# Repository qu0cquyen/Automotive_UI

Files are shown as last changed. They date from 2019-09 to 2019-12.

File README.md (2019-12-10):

# Automotive_UI (Pulse Sensor - SEN 11574)
<html>
	<head></head>
	<body>
		<h3>System Diagram</h3><hr/>
		<p align='center'>Final</p>
		<h3>Introduction</h3> <hr/>
		<p>Pulse Sensor - SEN 11574 can be used to keep tracking the pulse and provide BMP (Beat per minute) readings which is useful under the medical circumstances when it comes to monitoring patient's health. In this document, I will be sharing my personal experience on how to create a development platform for obtaing the readings from the sensor. This document will only provide simple instructions and for study purpose.  </p>
		<h2>Table of Contents<hr/></h2>
		<ol>
			<li><a href='#Bud'>Budget</a></li>
			<li><a href='#TC'>Time Commitment</a></li>
			<li><a href='#MA'>Mechanical Assembly</a></li>
			<li><a href='#PCB'>PCB/Soldering</a></li>
			<li><a href='#PP'>Power Up and Production Testing</a></li>
			<li><a href='#EC'>Enclosure</a></li>
			<li><a href='#RF'>Reference</a></li>
		</ol>
	<ol>
		<li><h3 id='Bud'>Budget<hr/></h3></li>
		<p>To implement this project. There are some components and equipments are used: 
					<table>
						<tr><td>Raspberry Pi 4 - 32GB SDCard</td><td align="right">CDN$ 134.99</td></tr>
						<tr><td>ADS1015 Converter</td><td align="right">CDN$ 33.89</td></tr>
						<tr><td>Pulse Sensor - SEN 11574</td><td align="right">CDN$ 48.43</td></tr>
						<tr><td><a href='https://raw.githubusercontent.com/qu0cquyen/Automotive_UI/master/electronics/Project_Fritzing.fzz'>Customized PCB</a></td><td align="right">CDN$ 28.7</td></tr>
						<tr><td>Headers </td><td align="right">CDN$ 33.9</td></tr>
						<tr><td><a href='https://www.tinkercad.com/things/gwDEV7c7vIV-smashing-wolt/edit'>Customized Enclosure</a></td><td align="right">CDN$ 30.00</td></tr>
						<tr><td>Total</td><td align="right">CDN$ 308.82</td></tr>
					</table>
			The total price is assumed that we do not possess any components aside from Standley tool kit (included jumper wires)
		</p>
		<li><h3 id='TC'>Time Commitment<hr/></h3></li>
		<p>
		&emsp;&emsp;This time commitment is writtent based on the assumption of not having any components except the tool kit and no experience of PCB designing. The total amount of time to accomplish this project is approximately 31 hours. This included waiting time for all components and equipments are shipped and gathered. For some side-work such as Project Selection (30 minutes), Proposal, Meeting and Budget will take roughly one to two hours to finish each of them. </p>
		<p>&emsp;&emsp;Fritzing software is used to design the Breadboard and PCB. Both designs are pretty straight forward, all we need to do is to properly wire up all the components. However, the software does not include Hearbeat sensor and ADS1015 converter. You can download these 2 components for Fritizing with this links: 
		<ul>
			<li><a href='https://raw.githubusercontent.com/adafruit/Fritzing-Library/master/parts/Adafruit%20ADS1015%2012Bit%20I2C%20ADC.fzpz'>ADS1015</a></li>
			<li><a href='https://raw.githubusercontent.com/WorldFamousElectronics/Fritzing_PulseSensor_Files/master/Pulse%20Sensor.fzpz'>Pulse Sensor</a></li>
		</ul>
		In additional, there are two things we need to adjust for the PCB design are the size of Vias and Wires, 0.9 and 16 mil accordingly. This process should take around 4 hours. A personal design can be found from this <a href='https://github.com/qu0cquyen/Automotive_UI/blob/master/electronics/Project_Fritzing.fzz'>link</a>. </p>
		<p>&emsp;&emsp;After having both designs are done, next all the necessary components will be hooked up on the breadboard first based upon the breadboard designed which is done on Fritizing. The amount of time should be spent on this process is 30 minutes to 1 hour. </p>
		<p>&emsp;&emsp;Once we have everything ready up to this point, building an enclosure for our components will be our next step. Personally, this can be seen as the most annoyed process in the whole project; apart from coming up with a design which can cover all the parts of our components, we also need to have a inctricate design in order to fit in all the parts together. In this process I spent about 21 hours for both designing and 3D printing the enclosure. During the process, I used school and 3rd-party 3D printing service outside the school to accelerate my process. There is a number of faulty designs have been made due to mistaking measurements, therefore, I would recommend that you should research or ask experts who are able to give some suggestions in details measurement, if you want all the parts of the enclosure can perfectly fit to each other.</p>
		<li><h3 id='MA'>Mechanical Assembly<hr/></h3></li>
		<p>In order to get the reading from the sensor. There are several steps we should take to create our development platform.</p>
		<h4>Step 1: Download and Install IOS for Raspberry Pi.</h4>
		<p>The image that we are going to use for our Pi is Raspbian. You can download from this <a href='https://downloads.raspberrypi.org/raspbian_full/images/raspbian_full-2019-09-30/2019-09-26-raspbian-buster-full.zip'>link</a></p>
		<p>Aside from downloading the image, we also need to download another software which helps to write the image to a SD card and this card is used by the Raspberry Pi.  You can download from here: https://www.balena.io/etcher/</p>
		<p align='center'>animated</p>
		<h4>Step 2: Boost up Operating System</h4>
		<p>After writing the image to the SD card, it is time to boost up our Pi Operating System. First, we need to do some configuration if you want your Pi to be able to work remotely.</p>
		<p>&emsp;&emsp;- Open the terminal and type in: <b>sudo raspi-config</b></p>
		
		
		<p>&emsp;&emsp;&emsp;&emsp;Enable SSH, VNC and I2C features</p>
		<p>&emsp;&emsp;- Next we will set up the WIFI: </p>
		<p>&emsp;&emsp;&emsp;&emsp;In the terminal type in: <b>sudo nano /etc/wpa_supplicant/wpa_supplicant.conf</b></p>
		<p>&emsp;&emsp;&emsp;&emsp;&emsp;&emsp;Types in the following lines: </p>
		<p>&emsp;&emsp;&emsp;&emsp;&emsp;&emsp;&emsp;&emsp;<b>network={<br/>
		&emsp;&emsp;&emsp;&emsp;&emsp;&emsp;&emsp;&emsp;&emsp;&emsp;&emsp;&emsp;&emsp;&emsp;ssid="YOUR WIFI NAME"<br/>
		&emsp;&emsp;&emsp;&emsp;&emsp;&emsp;&emsp;&emsp;&emsp;&emsp;&emsp;&emsp;&emsp;&emsp;password="WIFI PASSWORD"<br/>
		&emsp;&emsp;&emsp;&emsp;&emsp;&emsp;&emsp;&emsp;&emsp;&emsp;&emsp;&emsp;&emsp;&emsp;priority=999<br/>
		&emsp;&emsp;&emsp;&emsp;&emsp;&emsp;&emsp;&emsp;&emsp;&emsp;&emsp;&emsp;&emsp;}</b></p>
		<p>&emsp;&emsp;Notice the "priority" line, when you implement this line the Raspberry Pi will look for the network which has the highest priority first to connect, if the network is not avaiable it will automatic connect to any network that has accessed before.</p>
		<h4>Step 3: Assemble our components to Pi: </h4>
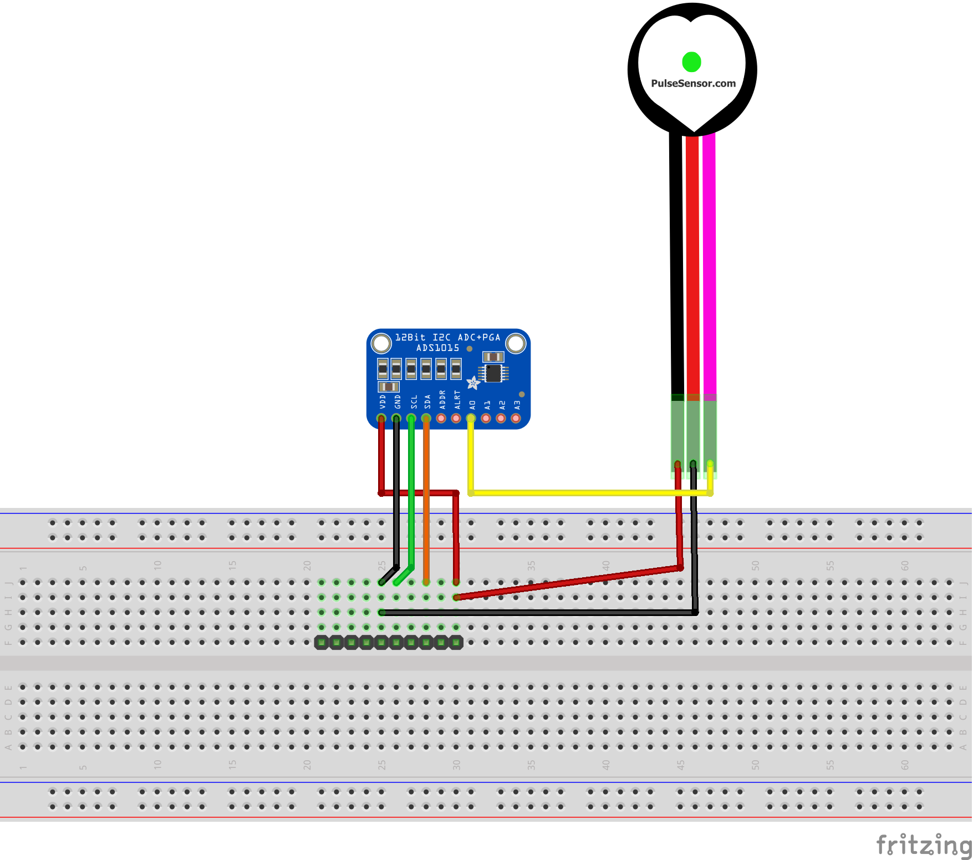
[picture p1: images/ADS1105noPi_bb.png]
		
		
		<h4>Step 4: Coding</h4>
		<p>&emsp;&emsp;You can refer to the code fragment from here: https://github.com/udayankumar/heart-rate-raspberry-pi. Code is written by using Python language.</p>
		<h4>Step 5: Result</h4>
		<p>&emsp;&emsp;If you are flowing those steps above, you should be able to get the reading from the sensor.</p>
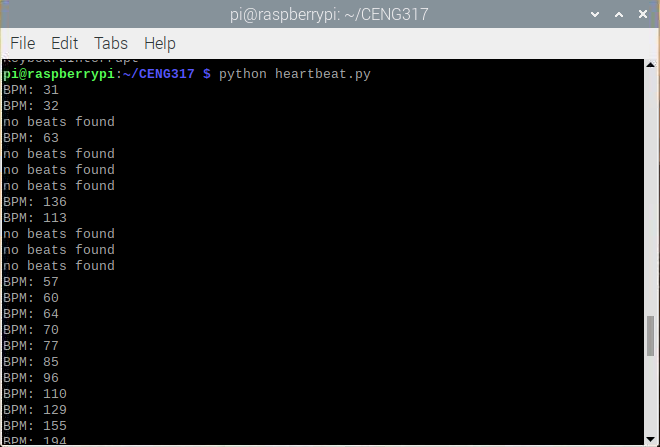
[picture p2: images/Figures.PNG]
		
		<li><h3 id='PCB'>PCB/Soldering<hr/></h3></li>
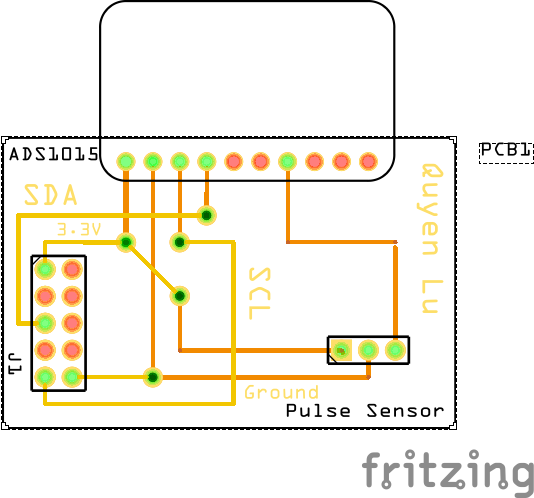
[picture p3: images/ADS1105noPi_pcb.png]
		
		
		<li><h3 id='PP'>Power Up and Production Testing<hr/></h3></li>
		
		<p>&emsp;&emsp;The picture above shows the voltage measurement that I measured on PCB section where the header connects to the Pi, and the Pi supplies the voltage for PCB in order to connect the remainder parts on the PCB board. Since I am using 3.3V to power up my PCB; therefore, when I measure the voltage on the other side of the PCB, the voltage meter gives me the reading of 3.3V.</p>
		
		<p>&emsp;&emsp;I did the same procedure of measuring as I mentioned above, however, this time I measured at the Sensor part. This measurement demonstrates that all the sections on the PCB are connected to each other, since I am able to get voltage reading (3.3V) when I measure on the Sensor part. This means the Pi is providing 3.3V for the whole PCB. </p>
		
		<p>&emsp;&emsp;When everything is connected to each other, you will be able to see the light on the Sensor is up. </p>
		
		<p>&emsp;&emsp;After having everything is hooked up, this is the phase that I tested whether or not my Sensor is working properly. By getting the BMP on the terminal, this proves that my Sensor is working as I expected by displaying the BMP when I place my finger on the Sensor.</p>
		<li><h3 id='EC'>Enclosure<hr/></h3></li>
		<p>&emsp;&emsp;To design the Enclosure, you can use either Sketchup or Tinkercad to desgin your own enclosure. After your design is done, you should generate a .STL file and feed to Cura - A software which is used for 3D printing purpose. Cura will provide us an insight information what need to be used/done in order to print out the real case. When you finish revewing configuration information, Cura can help you export a .G file which is used for 3D printer to continue printing our work. The printing process usually takes up around from 2 upto 8 hours depends on your design. Finally, when we have our case is properly printed, it is time to put our components into the enclosure. The images below is my personal enclosure. <b>Notice: There is still some minor mistakes, please reconsider if you are going to use this design.</b> You can find my design files here:
			<a href='https://github.com/qu0cquyen/Automotive_UI/blob/master/mechanical/Final_Bottom_Case_Enclousre.stl'>Bottom</a>
		<a href='https://github.com/qu0cquyen/Automotive_UI/blob/master/mechanical/Final_Middle_Case_Enclosure.stl'>Top</a></p>
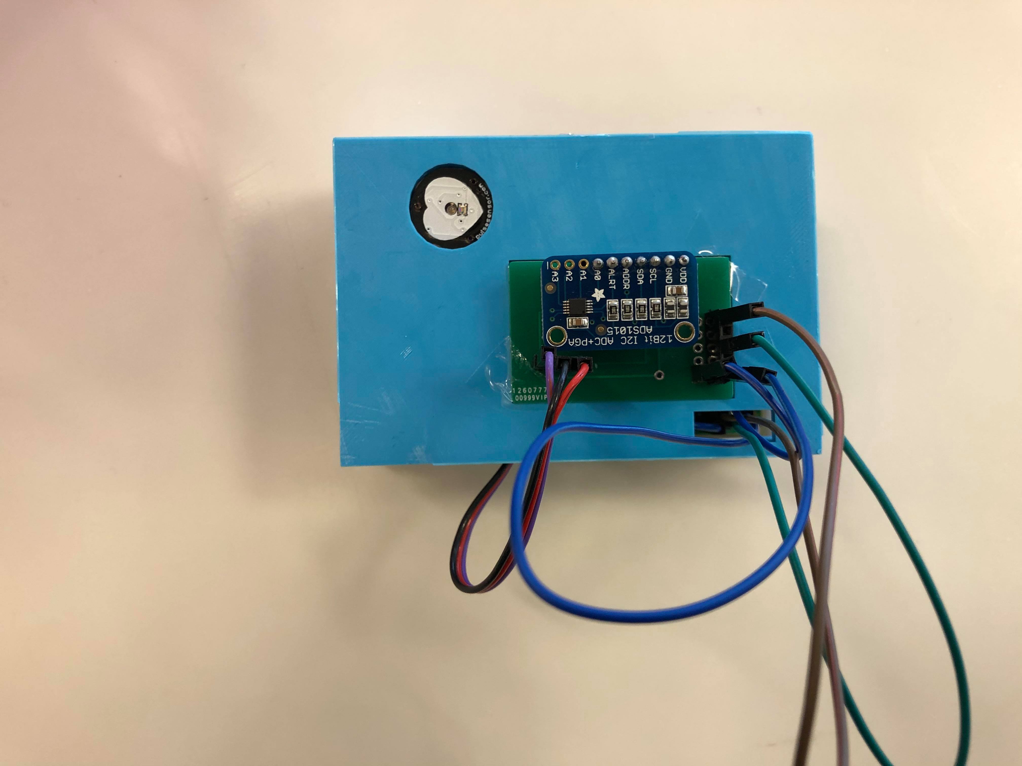
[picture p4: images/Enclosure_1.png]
		
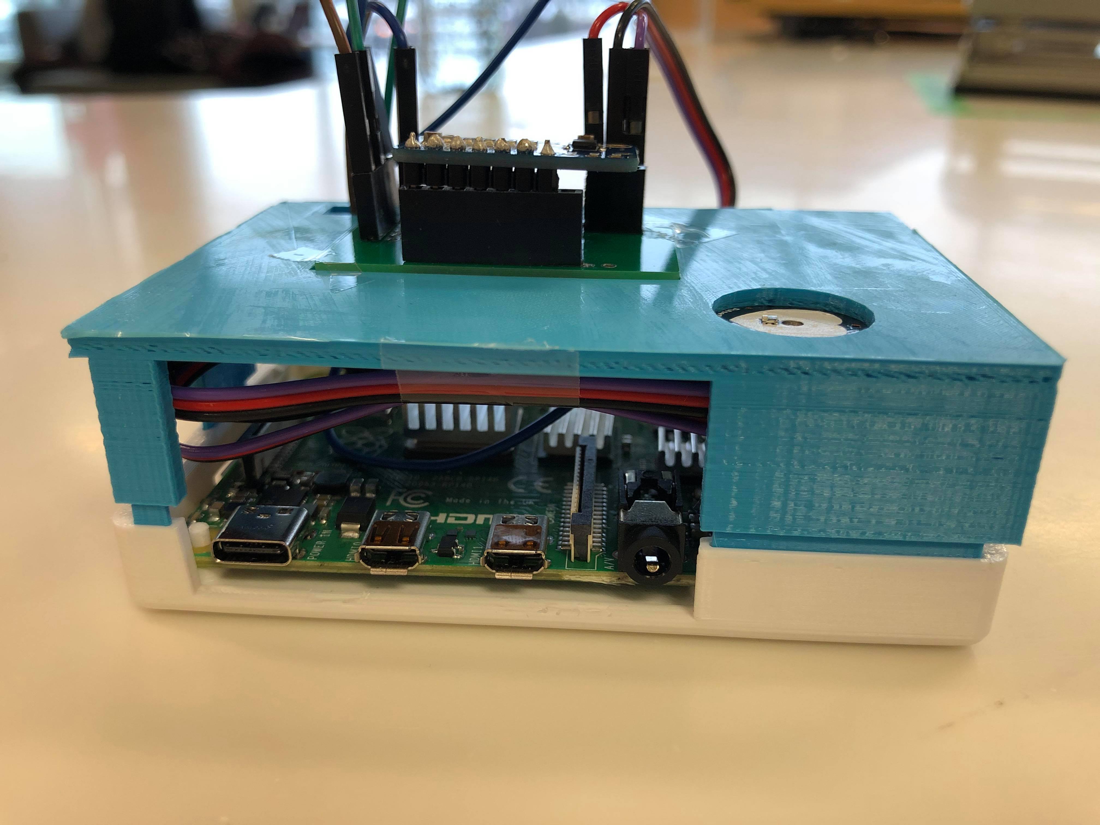
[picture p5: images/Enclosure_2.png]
		
	<li><h3 id='RF'>Reference: <hr/></h3></li>
	<p>Marinos, A. (2018, October 18). Etcher: Now with multi-write and Compute Module support! Retrieved from https://www.balena.io/blog/etcher-now-with-multi-write-and-compute-module-support/.</p>
	<p>Staff, M. (2018, April 5). How to Boot to Command Line and SSH on Raspberry Pi. Retrieved from https://www.digikey.com/en/maker/blogs/2018/how-to-boot-to-command-line-and-ssh-on-raspberry-pi.</p>
	</ol>
	</body> 
</html>

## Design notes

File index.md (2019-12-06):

<!DOCTYPE html> 
<html>
	<head>
	</head>
	<body>
		<h2>Blog Project CENG317 </h2>
		<h3>December 5th, 2019</h3>
		<p>Uploads final enclosures design files</p>
		<a href='https://github.com/qu0cquyen/Automotive_UI/blob/master/mechanical/Final_Bottom_Case_Enclousre.stl'>Bottom Enclosure</a><br/>
		<a href='https://github.com/qu0cquyen/Automotive_UI/blob/master/mechanical/Final_Middle_Case_Enclosure.stl'>Mid Enclosure</a>
		<h3>December 3rd, 2019</h3>
		<p>After carefully measuring, I have my final enclosure which holds my PCB and Heartrate sensor. The amount of time spending for this whole 3D printing process is approximately 21 hours (included the failed printing)</p>
		<p>These pictures are my final enclosure: </p>
		<ul>
			
			
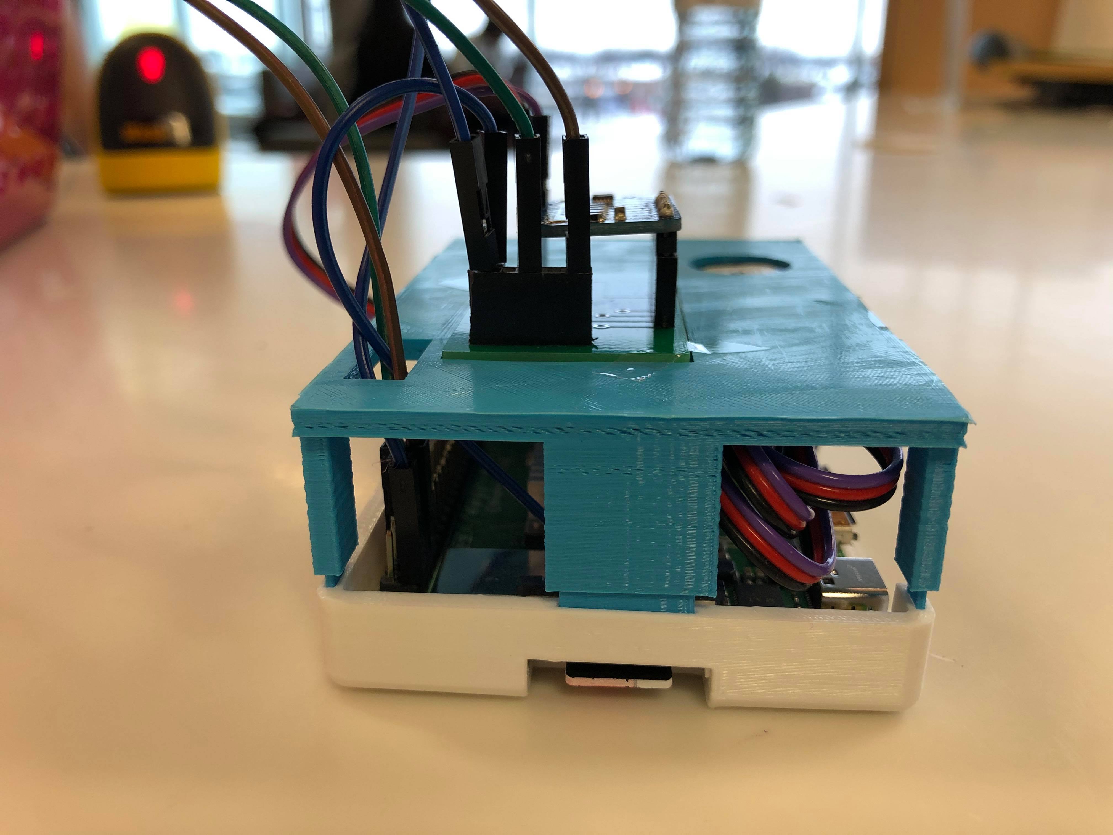
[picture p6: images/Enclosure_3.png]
			
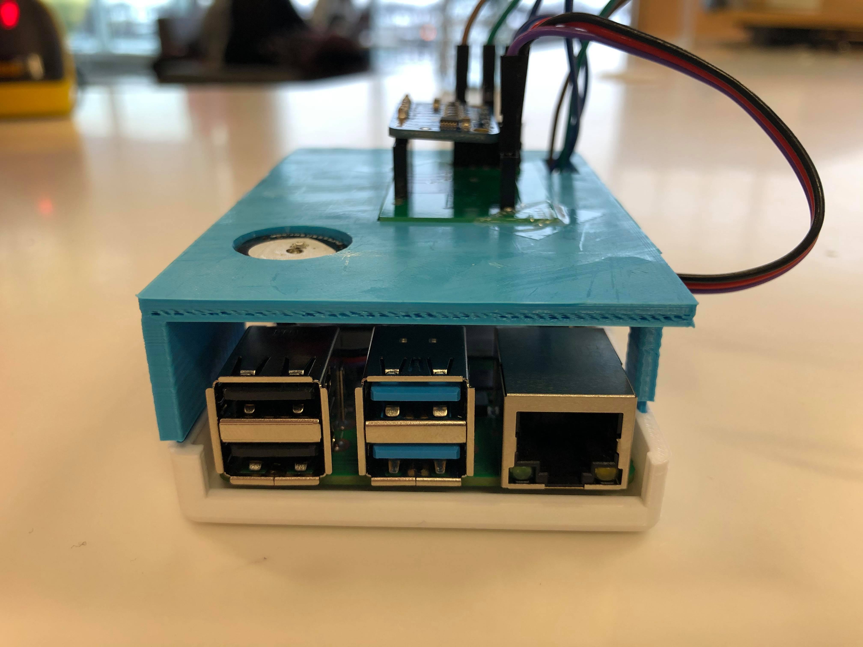
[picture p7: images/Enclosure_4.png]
			
		</ul>
		<p>These images below are the failure (I threw some of them): </p>
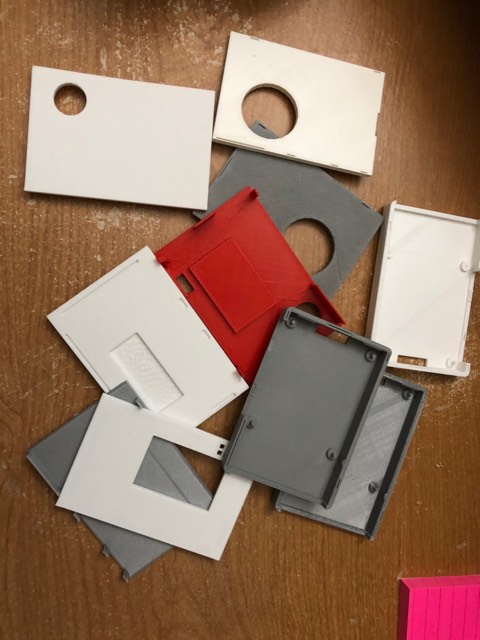
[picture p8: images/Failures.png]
		</li>
		<h3>November 28th, 2019</h3>
		<p>Today, I tried to print out a redesign case for the project. It starts giving out a result, however, there are still some problems, for example, there are some stands in the middle part of the case that will fit into some holes on the bottom of the case; since the stands are too long and thin which leads them to be easy to get broken off. Additionally, the wires are too long that make assembling process is much harder. At this moment, I am working on another design that will have enough space for storing the wires and have all the stands thicker.</p> 
		
		<h3>November 26th, 2019</h3>
		<p>This week we are going to present our project in terms of hardware platform. Presentation will be attached below: </p> 
		<ul>
			<li><a href='https://github.com/qu0cquyen/Automotive_UI/blob/master/documentation/Automotive_UI_Presentation.pptx'>Automotive_UI_Presentation (Power Point)</a></li>
			<li><a href='https://github.com/qu0cquyen/Automotive_UI/blob/master/documentation/Automotive_UI_Presentation.pdf'>Automotive_UI_Presentation (PDF)</a></li>
		</ul>
		<h3>November 22th, 2019</h3> 
		<p>I have just received my customer Pi case from third party service. However, the results are not what I expected due to the wrong measurement between the holes size and the stands size which make them cannot fit (clip) together. An adjustment of measurements has been made and I am waiting for the next printing results. </p>
		 <br/> 
		 
		<h3>November 19th, 2019</h3> 
		<p>Since there is a significant number of 3D printer reservations, I was not able to use the printer for the maximum two hours. I could only use the printer for one hour in order to print one side of my case. Unfortunately, as the come out result was not what I expected, then I realized that I messed up my measurement as well as the shapes of my case.</p> 
		<p>	Nonetheless, I managed to fix up my design at the moment I am writing this blog. The problem that I am having right now is the amount of time that I have to spend for making my whole case is around 9 hours 30 minutes. This process can be speeded up by printing each part separately, this may save approximate 2 hours compares to the printing the whole case as the original intention. In addition, my design is sent to the prototype lab to have them to help me in printing the physical case. </p> 
		<p> All the design files can be found in this blog entry </p> 
		<ul> 
			<li>Custom Case: </li> 
			<a href='https://github.com/qu0cquyen/Automotive_UI/blob/master/mechanical/Project_Custom_Case.skp'>Case Design (.skp file)</a><br/>
			<a href='https://github.com/qu0cquyen/Automotive_UI/blob/master/mechanical/Project_Custom_Case.stl'>Case Design (.stl file)</a>
			<li>Custom Case (Top part): </li>
			<a href='https://github.com/qu0cquyen/Automotive_UI/blob/master/mechanical/Top_case_final.skp'>Top design (.skp file)</a><br/>
			<a href='https://github.com/qu0cquyen/Automotive_UI/blob/master/mechanical/Top_case_final.stl'>Top design (.stl file)</a>
			<li>Custom Case (Middle part): </li>
			<a href='https://github.com/qu0cquyen/Automotive_UI/blob/master/mechanical/Mid_case_final.skp'>Middle design (.skp file)</a><br/>
			<a href='https://github.com/qu0cquyen/Automotive_UI/blob/master/mechanical/Mid_case_final.stl'>Middle design (.stl file)</a>
			<li>Custom Case (Bottom part): </li>
			<a href='https://github.com/qu0cquyen/Automotive_UI/blob/master/mechanical/Bottom_case_final.skp'>Bottom design (.skp file)</a><br/>
			<a href='https://github.com/qu0cquyen/Automotive_UI/blob/master/mechanical/Bottom_case_final.stl'>Bottom design (.stl file)</a>
		</ul>
		<h3>November 14th, 2019</h3>
		<p>	According to the schedule, we are at the PCB power up stage of the project right now. This
		means we are following what we have set for the project schedule. Even though we have dealt with some PCB connectivity problems, we are able to solve the issues and have it functions as we expect under the guidances of the professors in prototype lab. </p>
		<p>	In terms of finance, we have to pay around $20 for the headers which are used to attached and make connections between pins on PCB. The follwing pictures are captured to show the working PCB and running codes: </p>
		<ul>
			<li>Physical View of Functioning PCB:</li>
				
			<li>Running Code of Functioning PCB:</li>
				
		</ul>
		<h3>November 10th, 2019</h3>
		<p>Solder headers into PCB and measure the voltage goes in the PCB to make sure the PCB is working. </p>
		<ul>
			<li>Pi Section Measurement</li>
			
			<li>Sensor Section Measurement</li>
			
		</ul>
		<h3>October 31st, 2019</h3> 
		<p>Fortunately, my friend lends me a raspberry pi for running my project. The pi helps me records all the heart beat figures from hooking up all the necessary components on the breadboard and running codes </p> 
		<ul>
			<li>Breadboard connection</li>
			
			<li>Figures from the sensor</li>
			
			<li>Code Reference</li>
			<p>The codes that I used to get the heart beat figures can be found in this <a href='https://github.com/udayankumar/heart-rate-raspberry-pi'>link</a></p>
		</ul>
		<h3>October 15th, 2019</h3>
		<p>Hardware design:</p>
		<ul>
			<li>Breadboard</li>
			
			<li>Schematic</li>
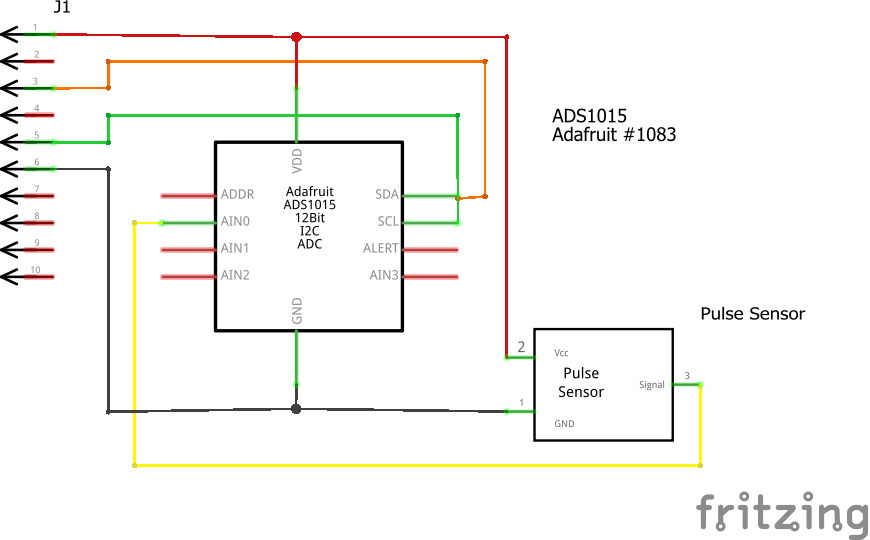
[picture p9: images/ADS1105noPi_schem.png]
			
			<li>PCB</li>
			
			<li><a href='https://github.com/qu0cquyen/Automotive_UI/blob/master/electronics/Project_Fritzing.fzz'>Firtzing File</a>
			</li>
		</ul> 
		<h3>October 1st, 2019</h3> 
		<p>Uploads proof of purchasing.</p>
		<p>There is a minor change in purchasing, instead of using the link that I provided in the budget. However, since the component (ADS1015) is going to be delivered in the middle of October, I have to change to another supplier who can deliver the component before the second week of October. A modification has been made in the budget file.</p>
		<h3>September 24th, 2019</h3>
		<p>After searching the suppliers for the components that I need. Then, I build a table with all information of the suppliers, part numbers, price and so forth in this table and named it as Project Budget. </p>
		<a href='https://github.com/qu0cquyen/Automotive_UI/blob/master/documentation/ProjectBudget.xlsx'>Project Budget (Excel file)</a><br>
		<a href='https://github.com/qu0cquyen/Automotive_UI/blob/master/documentation/ProjectBudget.pdf'>Project Budget (Pdf file)</a>
		<h3>September 17th, 2019</h3>
		<p>We had a discussion about the possibilities of finishing the project. Then we finalized how the project schedule should be looked alike.</p>
		<p>Changes the sensor that I am going to use for the project. The sensor that I will use is "Pulsesenor Heart Rate Beat Pulse Sensor Module" with an Analog to Digital converter (ADS1015). <a href='http://udayankumar.com/2016/05/17/heart-beat-raspberry/'>References</a></p>
		<a href='https://github.com/qu0cquyen/Automotive_UI/blob/master/documentation/ProjectSchedule.pdf'>Project Schedule</a>
		<h3>September 8th, 2019</h3> 
		<p>Do some research about Automotive_UI is being implemeted in the current products.</p>
		<p>Finish documentation</p>
		<ul>
			<li><a href='https://github.com/qu0cquyen/Automotive_UI/blob/master/documentation/ProjectProposalEmergensUIRev03.docx'>ProjectProposalEmergensUIRev03.docx</a></li>
			<li><a href='https://github.com/qu0cquyen/Automotive_UI/blob/master/documentation/ProjectProposalEmergensUIRev03.pdf'>ProjectProposalEmergensUIRev03.pdf</a></li>
			<li><a href='https://github.com/qu0cquyen/Automotive_UI/blob/master/documentation/ProposalContentEmergensUIRev03.xlsx'>ProjectContentEmergensUIRev03.xlsx</a></li>
			<li><a href='https://github.com/qu0cquyen/Automotive_UI/blob/master/documentation/ProposalContentEmergensUIRev03.pdf'>ProjectContentEmergensUIRev03.pdf</a></li>
		</ul>
		<h3>September 5th, 2019</h3>
		<p>Project <a href='https://qu0cquyen.github.io/Automotive_UI/'>repository</a> created</p>
	</body>
</html>

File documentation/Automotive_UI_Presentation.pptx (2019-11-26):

## Automotive UI

Quyen Lu – N01265429
CENG 317

## Introduction

- SEN 11574

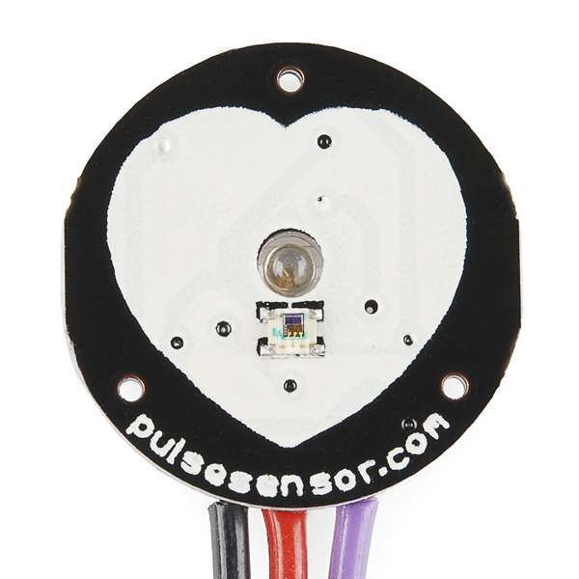
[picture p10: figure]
Image result for sen-11574 pulse sensor

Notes: Our project will concentrate on showing patient medical information on the dashboard as well as easing the communication between paramedics and hospital.
At the first place, I chose DS18B20 (Temperature Sensor) to work on this project. However, I found working on measuring the pulse is more interesting and I may learn a lot of from it. That’s why I decided to choose heartbeat measuring is my hardware platform.

## Budget

- SEN-11574: $48.43
- ADS1015: $33.89
- 10 copies of PCB: $38.67
- Enclosure: $34.00
Subtotal: $154.99

## Schedule

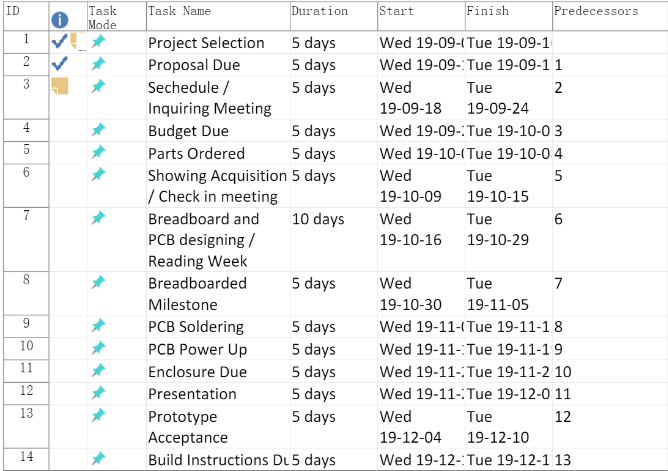
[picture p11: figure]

## Images

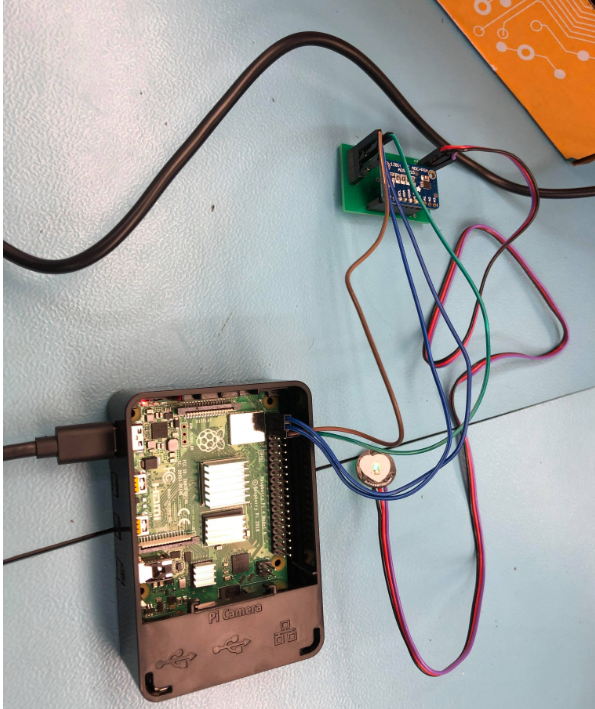
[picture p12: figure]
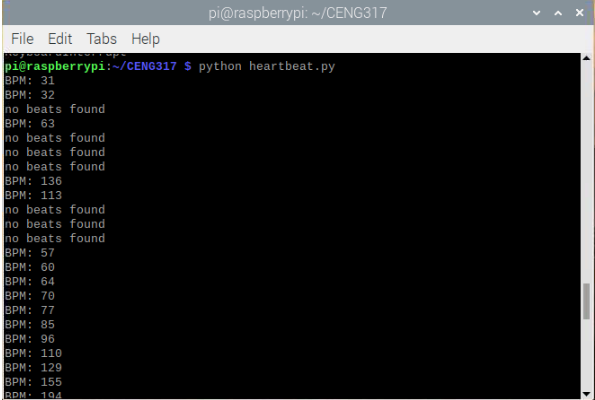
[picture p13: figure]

## Images

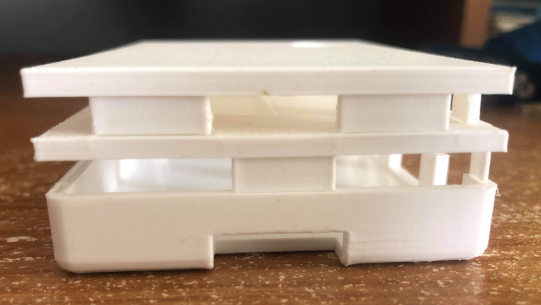
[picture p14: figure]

## Knowledge

- Electric Circuits – TECH 101
- Digital Fundamentals - TECH 103
- Technical C – TECH 153
- Introduction of Software Engineering – CENG 216
- Embedded Systems – CENG 252

## Thank you for your attention

- Q&A

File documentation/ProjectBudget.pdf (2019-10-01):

### Components for Automotive UI project

Total
Final Total Cost:

$52.77
$164.64
Components' name | Source | Part # | Price /Unit (CAD$)
SparkFun Electronics SEN-11574 | Digi Key | 1568-1247-ND | $35.78
Adafruit ADS1015 12-Bit ADC - 4 Channel with Programmable Gain Amplifier [ADA1083] | Amazon | ADA1083 | $16.99

Shipping (CAD$) | Taxes | Subtotal | Link | Comments
$8.00 | $4.65 | $48.43 | http://tiny.cc/9g89cz | This sensor will be used to get the heart rate reading
$13.00 | $3.90 | $33.89 | http://tiny.cc/tq6qdz | Convert Analog Signal to Digital Signal
$21.00 | $8.55 | $82.32

### Components for Automotive UI project

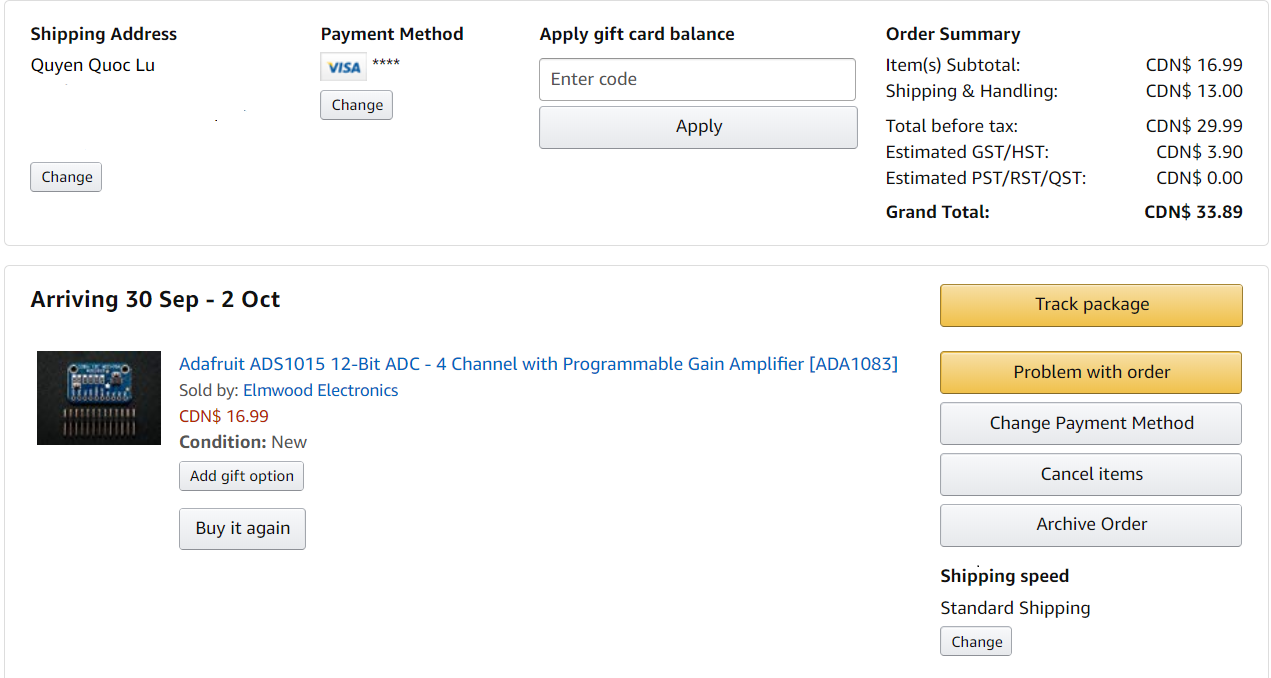
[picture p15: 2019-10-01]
images/ADS1105ProofEdited.png

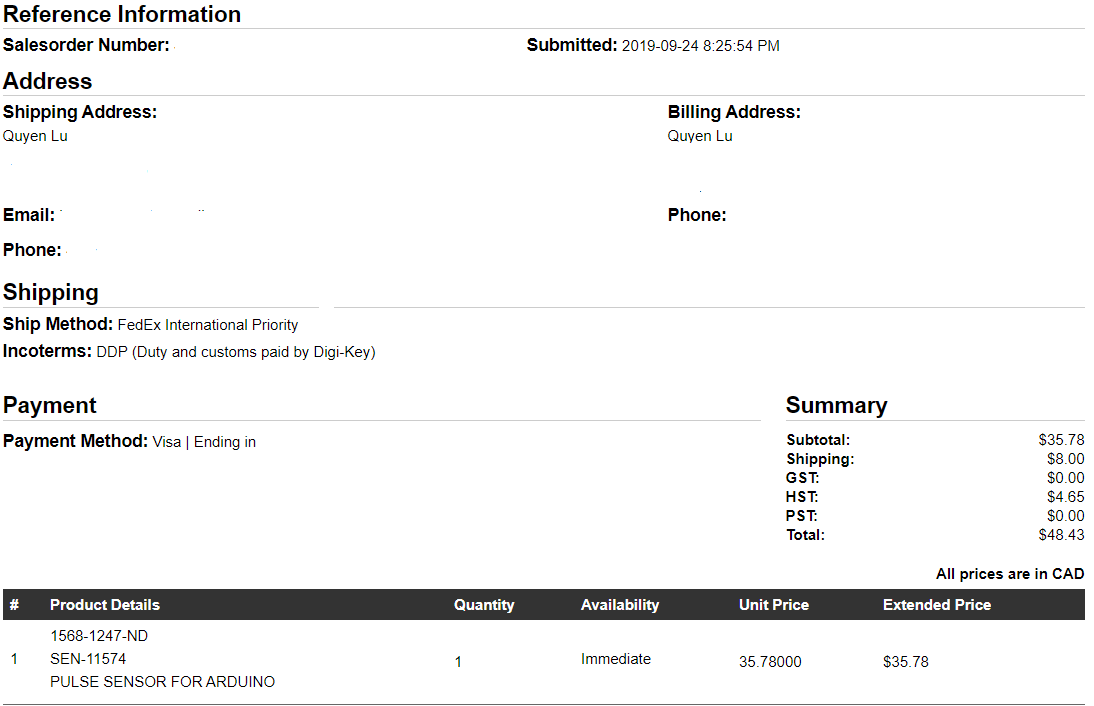
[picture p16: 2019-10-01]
images/PulseSensorProofEdited.png

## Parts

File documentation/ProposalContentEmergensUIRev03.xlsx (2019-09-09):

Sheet: DataEntry
Submission Date | 2019-09-10
Project Name | IoT for Automotive UI
Student Names | Kevin Lieng, Seung Min Song, Quyen Lu
Project repository | https://github.com/qu0cquyen/Automotive_UI
SensorsEffectors choices | Temperature Sensor (DS18B20)
The database will store | Temperature value of Engine, Speed, GPS location, Blood Pressure, Oxygen and Heart Rate
The mobile device functionality will include | Indicating patient's health information. Showing current ambulance's location. Emergency call. Engine Temperature value.
I will be collaborating with the following company/department | Professor Dennis Kappen.
My group in the winter semester will include | Kevin Lieng, Seung Min Song
50 word problem statement | Currently, the traditional way of transferring a patient's data between paramedics and doctors is considered too slow. Doctors usually have to wait for paramedics to arrive at the hospital in order to get the patient's status such as heart rate, blood pressure, oxygen and so on.
100 words of background | Aside from showing essential information such as speed, temperature and vehicle's location of a car dashboard, displaying patient's medical information can help the paramedics and doctors better predict and prepare before the patient arrives to the hospital or during the transfer process. By implementing those sensors above and having them show on a dashboard as well as conveying vital patient health information through application can assist both paramedics’ and doctors’ initiatives.
Current product APA citation | Drews, E. (2017, November 16). Car Dashboard UI & UX Concepts. Retrieved from https://medium.com/inspiration-supply/car-dashboard-ui-ux-concepts-d135959d963f (n.d.). 2019 A-Class Sedan. Retrieved from https://www.mercedes-benz.ca/en/vehicles/class/a-class/sedan
Existing research IEEE paper APA citation | Applin, S. A., Riener, A., & Fischer, M. D. (2015, October 28). Extending Driver-Vehicle Interface Research Into the Mobile Device Commons : Transitioning to (nondriving) passengers and their vehicles. Retrieved from https://ieeexplore.ieee.org/document/7310907
Brief description of planned purchases | Raspberry Pi 3, Temeperature Sensor (DS18B20),
Solution description | Paramedics will be more flexible in transferring the patients by monitoring patent's health information. Once paramedics get the health information on their dashboard, this information then will be uploaded and updated on the phone application. Doctors can have an overall patient's status while using the application. This way the docotors can get everything prepared before the patient arrived at the hospital.

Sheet: DataBase
Submission Date | Project Name | Student Names | Project repository | SensorsEffectors choices | The database will store | The mobile device functionality will include | I will be collaborating with the following company/department | My group in the winter semester will include | 50 word problem statement | 100 words of background | Current product APA citation | Existing research IEEE paper APA citation | Brief description of planned purchases | Solution description
2019-09-10 | IoT for Automotive UI | Kevin Lieng, Seung Min Song, Quyen Lu | https://github.com/qu0cquyen/Automotive_UI | Temperature Sensor (DS18B20) | Temperature value of Engine, Speed, GPS location, Blood Pressure, Oxygen and Heart Rate | Indicating patient's health information. Showing current ambulance's location. Emergency call. Engine Temperature value. | Professor Dennis Kappen. | Kevin Lieng, Seung Min Song | Currently, the traditional way of transferring a patient's data between paramedics and doctors is considered too slow. Doctors usually have to wait for paramedics to arrive at the hospital in order to get the patient's status such as heart rate, blood pressure, oxygen and so on. | Aside from showing essential information such as speed, temperature and vehicle's location of a car dashboard, displaying patient's medical information can help the paramedics and doctors better predict and prepare before the patient arrives to the hospital or during the transfer process. By implementing those sensors above and having them show on a dashboard as well as conveying vital patient health information through application can assist both paramedics’ and doctors’ initiatives. | Drews, E. (2017, November 16). Car Dashboard UI & UX Concepts. Retrieved from https://medium.com/inspiration-supply/car-dashboard-ui-ux-concepts-d135959d963f (n.d.). 2019 A-Class Sedan. Retrieved from https://www.mercedes-benz.ca/en/vehicles/class/a-class/sedan | Applin, S. A., Riener, A., & Fischer, M. D. (2015, October 28). Extending Driver-Vehicle Interface Research Into the Mobile Device Commons : Transitioning to (nondriving) passengers and their vehicles. Retrieved from https://ieeexplore.ieee.org/document/7310907 | Raspberry Pi 3, Temeperature Sensor (DS18B20), | Paramedics will be more flexible in transferring the patients by monitoring patent's health information. Once paramedics get the health information on their dashboard, this information then will be uploaded and updated on the phone application. Doctors can have an overall patient's status while using the application. This way the docotors can get everything prepared before the patient arrived at the hospital.

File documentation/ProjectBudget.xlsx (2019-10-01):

Components for Automotive UI project
Components' name | Source | Part # | Price /Unit (CAD$) | Shipping (CAD$) | Taxes | Subtotal | Link | Comments
SparkFun Electronics SEN-11574 | Digi Key | 1568-1247-ND | $35.78 | $8.00 | $4.65 | $48.43 | http://tiny.cc/9g89cz | This sensor will be used to get the heart rate reading
Adafruit ADS1015 12-Bit ADC - 4 Channel with Programmable Gain Amplifier [ADA1083] | Amazon | ADA1083 | $16.99 | $13.00 | $3.90 | $33.89 | http://tiny.cc/tq6qdz | Convert Analog Signal to Digital Signal
 |  | Total | $52.77 | $21.00 | $8.55 | $82.32
 |  | Final Total Cost: | $164.64

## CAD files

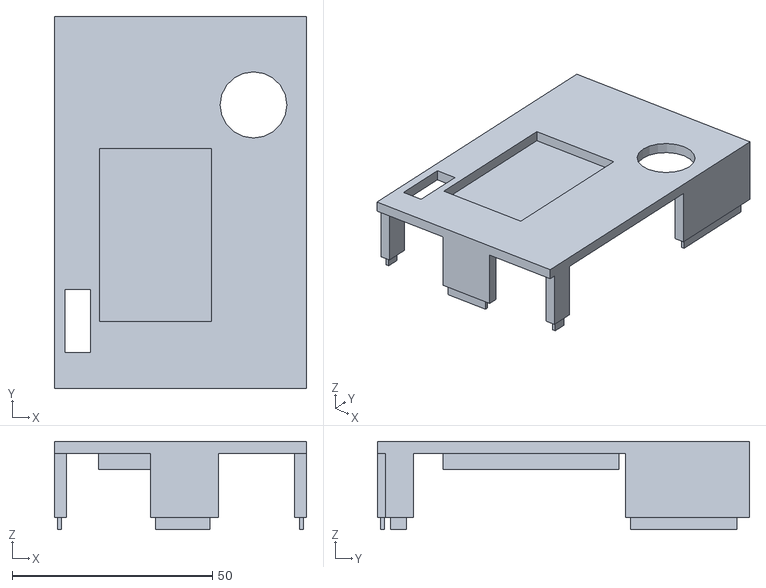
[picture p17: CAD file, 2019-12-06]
mechanical/Final_Middle_Case_Enclosure.stl
63.0 x 93.0 x 22.0

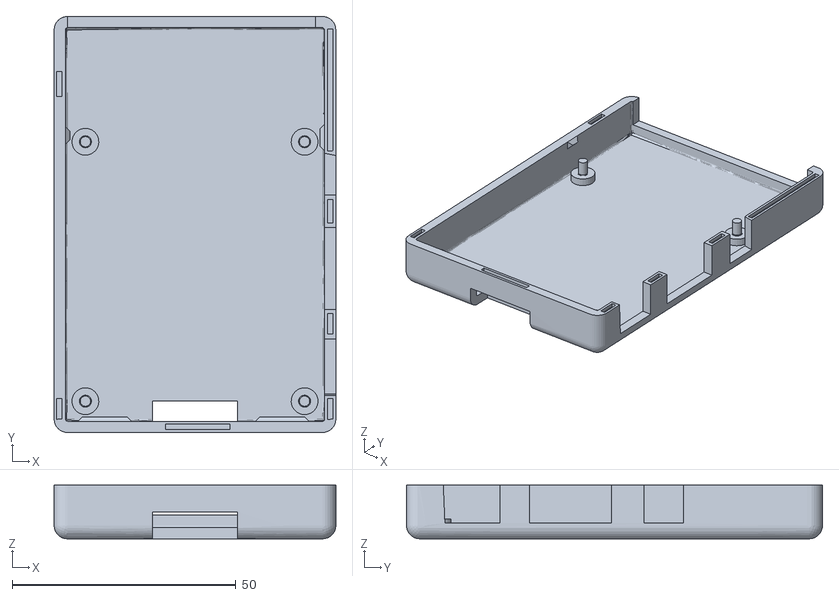
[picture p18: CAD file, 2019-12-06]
mechanical/Final_Bottom_Case_Enclousre.stl
63.0 x 93.0 x 12.0

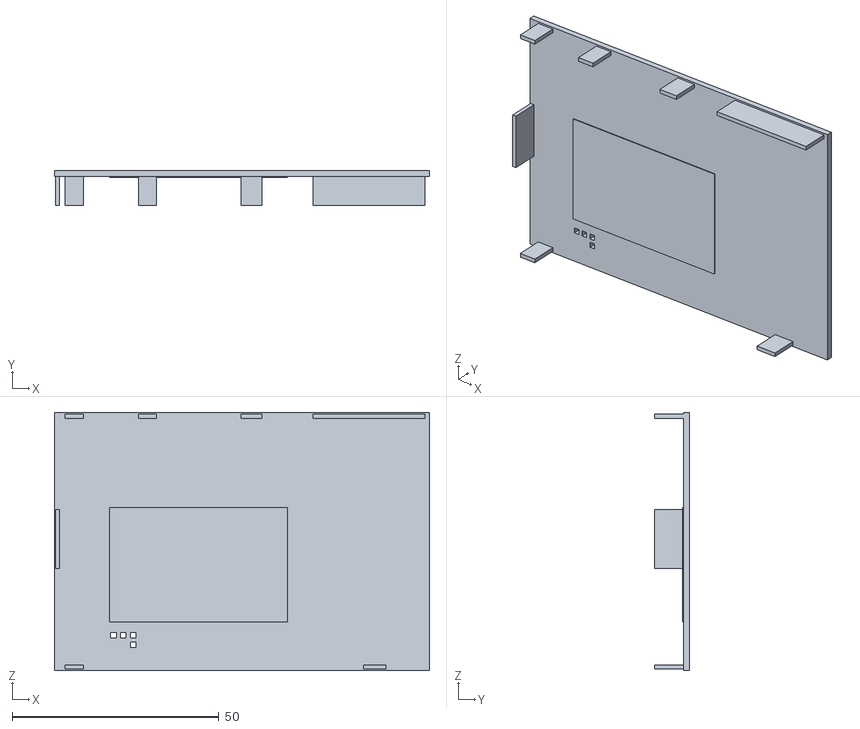
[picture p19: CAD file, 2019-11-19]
mechanical/Mid_case_final.stl
90.6 x 8.50 x 62.4

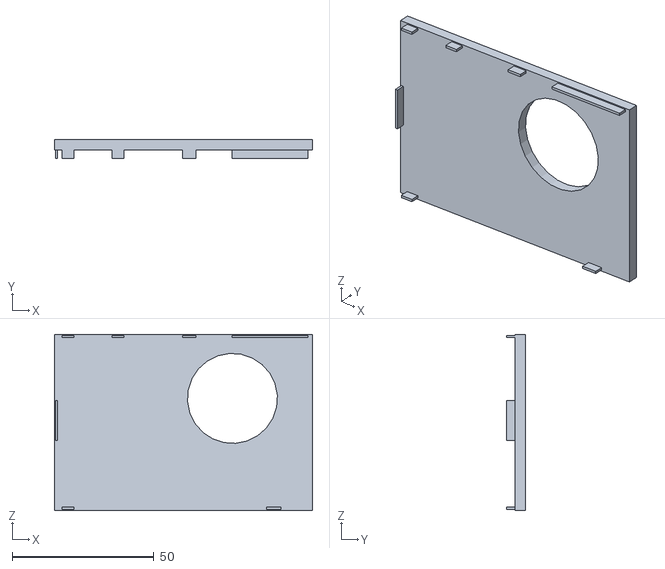
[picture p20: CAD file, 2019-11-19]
mechanical/Top_case_final.stl
91.1 x 6.60 x 62.3

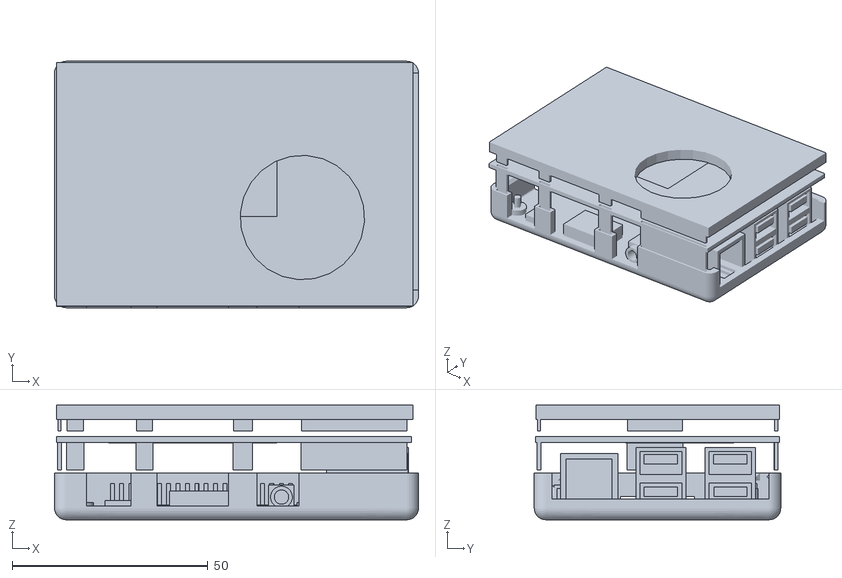
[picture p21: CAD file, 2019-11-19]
mechanical/Project_Custom_Case.stl
93.0 x 63.0 x 29.3

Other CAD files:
mechanical/Bottom_case_final.stl
mechanical/Bottom_case_final.skp
mechanical/Mid_case_final.skp
mechanical/Project_Custom_Case.skp
mechanical/Top_case_final.skp

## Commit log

2019-09-09 Proposal uploaded
    [ProposalContentEmergensUIRev03.xlsx]
2019-09-17 Change sensor
2019-09-24 Project Budget upload
    [ProjectBudget.xlsx]
2019-10-01 Update purchasing information
    [ProjectBudget.xlsx]
2019-10-15 Breadboard, Schematic and PCB project uploads
2019-10-15 Project Fritzing uploads
    [Project_Fritzing.fzz]
2019-10-21 Revise Fritizing files and PCB image
    [Project_Fritzing.fzz]
2019-10-21 Modified image link for PCB and Fix HTML code
2019-11-01 Uploads bread board demo of project and figures from the sensor
2019-11-11 Upload PCB Measurements
2019-11-15 PCB power up
2019-11-19 Case design upload
    [Project_Custom_Case.skp, Project_Custom_Case.stl]
2019-11-19 Case designs upload
    [Bottom_case_final.skp, Bottom_case_final.stl, Mid_case_final.skp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]
2019-11-24 Custom case upload
2019-11-26 Project Presentation Uploads (Power Point)
2019-11-26 Power Point contents change
2019-11-29 Remade case upload
2019-12-04 Final Enclosure uploads
2019-12-06 Enclosure uploads
    [Final_Bottom_Case_Enclousre.stl, Final_Middle_Case_Enclosure.stl]
